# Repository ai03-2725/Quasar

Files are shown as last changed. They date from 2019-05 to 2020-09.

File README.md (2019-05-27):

# Quasar
A replacement controller for the IBM Model M Space Saving keyboard

#### In light of recent claims that I am 100% liable for any of my open source PCBs, I am adding this disclaimer.
#### I provide these PCBs as a reference for designing keyboard PCBs. Using them within your projects will require a will to do research of one's own and to learn the workings of them, potentially fixing issues if they exist.
# I provide these PCBs without liability and without any guarantees regarding functionality, as expressed in the MIT license under which all of these PCBs are licensed.

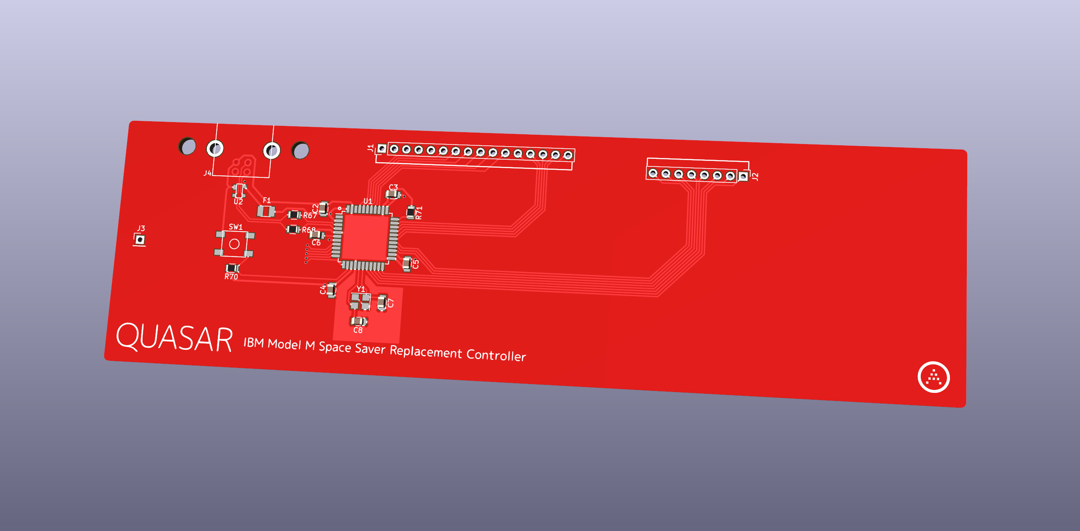
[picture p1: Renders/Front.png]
Render


### Features 
* ATmega32u4-based
* USB-B

### Credits
* Antonizoon's [Model M USB controller research](https://github.com/antonizoon/antonizoon.github.io/wiki/IBM-Model-M-USB-Controller)
* Phosphorglow's [SSK matrix reverse engineering](https://deskthority.net/viewtopic.php?t=8149)
* 9595's [Model M controller dimensions](http://ps-2.kev009.com/ohlandl/keyboard/Keyboard.html)
* Lmorchard's [Model M USB controller research](http://blog.lmorchard.com/2016/02/21/modelm-controller/#secrets-of-2kro-matrices)

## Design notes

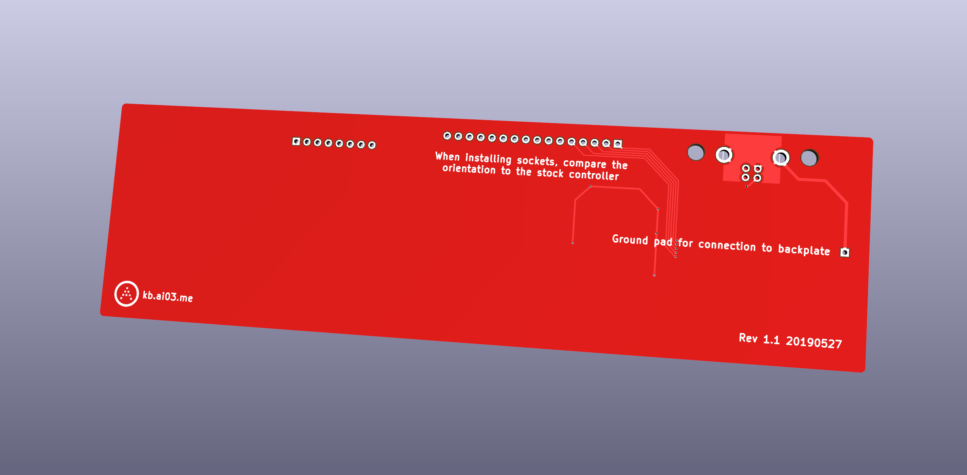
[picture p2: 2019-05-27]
Renders/Back.png

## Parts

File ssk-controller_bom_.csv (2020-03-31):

Component | Description | Part | References | Value | Footprint | Quantity Per PCB | Datasheet
1 | Unpolarized capacitor, small symbol | C_Small | C3 C4 C5 | 0.1uF | C_0805_2012Metric | 3
2 | Unpolarized capacitor, small symbol | C_Small | C2 | 10uF | C_0805_2012Metric | 1
3 | Unpolarized capacitor, small symbol | C_Small | C6 | 1uF | C_0805_2012Metric | 1
4 | Unpolarized capacitor, small symbol | C_Small | C7 C8 | 22pF | C_0805_2012Metric | 2
5 | Unpolarized capacitor, small symbol | C_Small | C1 | 4.7nF | C_0805_2012Metric | 1
6 | Diode, small symbol | D_Small | D1 | 1N4007 | D_SOD-123 | 1 | ~
7 | Resettable fuse, polymeric positive temperature coefficient, small symbol | Polyfuse_Small | F1 | 500mA | Fuse_1206_3216Metric | 1
8 | Generic connector, single row, 01x01, script generated (kicad-library-utils/schlib/autogen/connector/) | Conn_01x01 | J3 | Conn_01x01 | PinHeader_1x01_P2.54mm_Vertical | 1 | ~
9 | Generic connector, single row, 01x08, script generated (kicad-library-utils/schlib/autogen/connector/) | Conn_01x08 | J2 | Conn_01x08 | PinHeader_1x08_P2.54mm_Vertical | 1 | ~
10 | Generic connector, single row, 01x16, script generated (kicad-library-utils/schlib/autogen/connector/) | Conn_01x16 | J1 | Conn_01x16 | PinHeader_1x16_P2.54mm_Vertical | 1 | ~
11 | Generic connector, single row, 01x02, script generated (kicad-library-utils/schlib/autogen/connector/) | Conn_01x02 | J5 | Solenoid | PinHeader_1x02_P2.54mm_Vertical | 1 | ~
12 | Generic connector, single row, 01x03, script generated (kicad-library-utils/schlib/autogen/connector/) | Conn_01x03 | J6 | Solenoid_Signal | JST-SR-3 | 1 | ~
13 | USB Type B connector | USB_B | J4 | USB_B | TE-292304-2 | 1 | ~
14 | N-MOSFET transistor, gate/source/drain | Q_NMOS_GSD | Q1 | Q_NMOS_GSD | SOT-23 | 1 | ~
15 | Resistor, small symbol | R_Small | R2 | 100 | R_0805_2012Metric | 1
16 | Resistor, small symbol | R_Small | R70 | 10k | R_0805_2012Metric | 1
17 | Resistor, small symbol | R_Small | R1 R3 | 1M | R_0805_2012Metric | 2
18 | Resistor, small symbol | R_Small | R71 | 1k | R_0805_2012Metric | 1
19 | Resistor, small symbol | R_Small | R67 R68 | 22 | R_0805_2012Metric | 2
20 | Push button switch, generic, two pins | SW_Push | SW1 | SW_Push | SKQG-1155865 | 1
21 | 16MHz, 16kB Flash, 1.25kB SRAM, 512B EEPROM, USB 2.0, TQFP-44 | ATmega32U4-AU | U1 | ATmega32U4-AU | TQFP-44_10x10mm_P0.8mm | 1 | http://ww1.microchip.com/downloads/en/DeviceDoc/Atmel-7766-8-bit-AVR-ATmega16U4-32U4_Datasheet.pdf
22 |  | PRTR5V0U2X | U2 | PRTR5V0U2X | SOT143B | 1
23 | Four pin crystal, GND on pins 2 and 4 | Crystal_GND24 | Y1 | 16Mhz | Crystal_SMD_3225-4Pin_3.2x2.5mm | 1
Component Groups: | 23
Component Count: | 28
Fitted Components: | 28
Number of PCBs: | 1
Total components: | 28
Schematic Version:
Schematic Date:
BoM Date: | 3/31/2020 9:19:48 AM
Schematic Source: | C:\Users\Ryota Goto\Documents\GitHub\Quasar\ssk-controller.sch
KiCad Version: | Eeschema (5.1.4)-1

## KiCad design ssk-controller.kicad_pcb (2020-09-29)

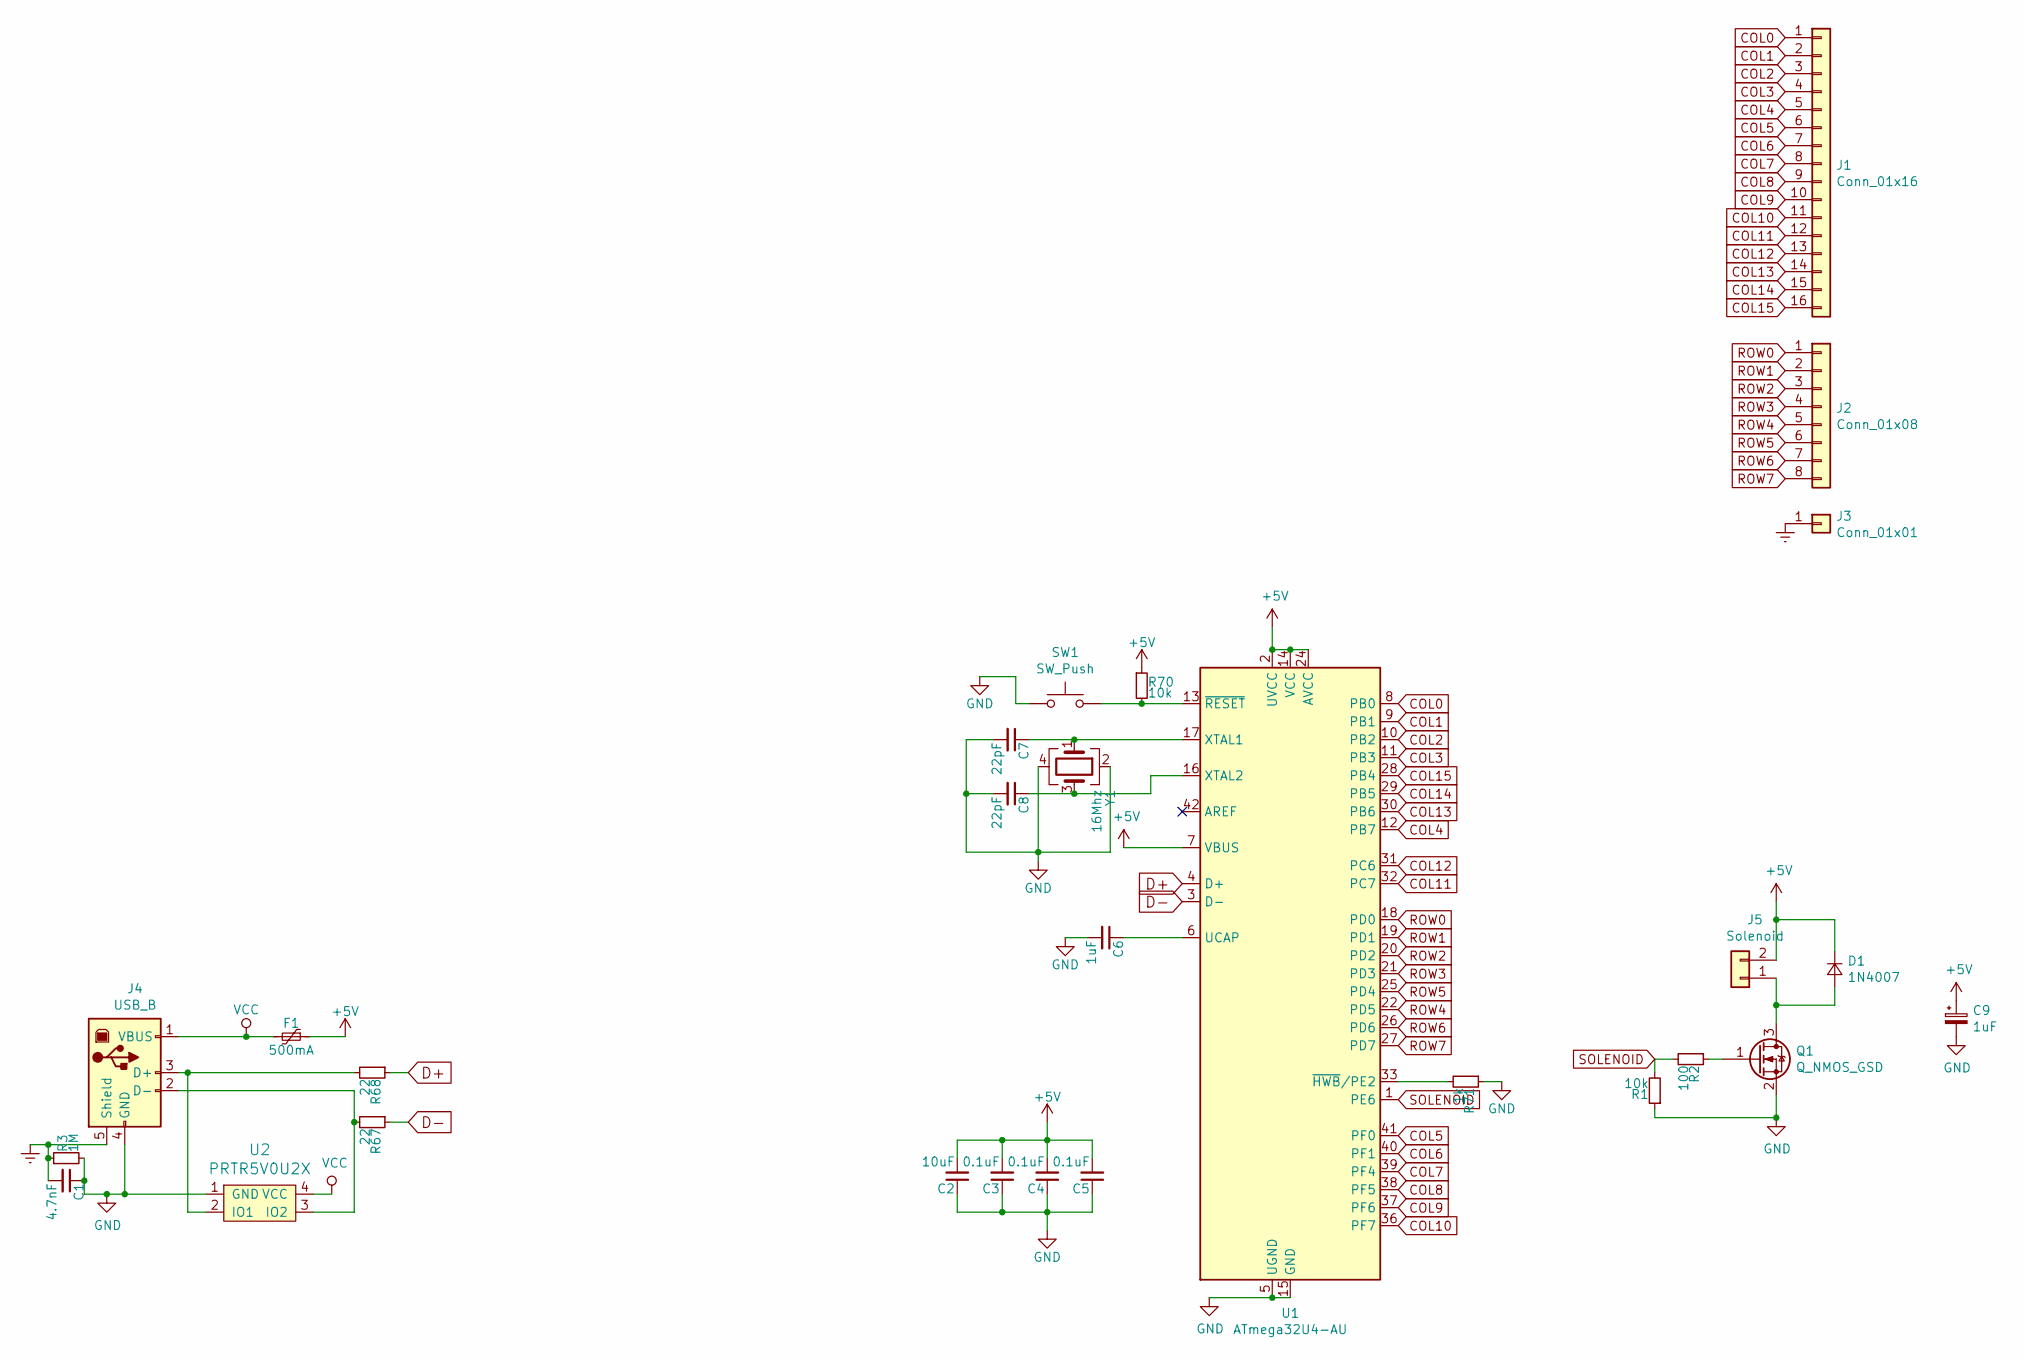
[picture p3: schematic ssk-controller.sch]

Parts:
C1: 4.7nF; C_0805_2012Metric
C2: 10uF; C_0805_2012Metric
C3, C4, C5: 0.1uF; C_0805_2012Metric
C6: 1uF; C_0805_2012Metric
C7, C8: 22pF; C_0805_2012Metric
C9: 1uF; CP_EIA-3216-18_Kemet-A
D1: 1N4007; D_SOD-123
F1: 500mA; Fuse_1206_3216Metric
J1: Conn_01x16; PinHeader_1x16_P2.54mm_Vertical
J2: Conn_01x08; PinHeader_1x08_P2.54mm_Vertical
J3: Conn_01x01; PinHeader_1x01_P2.54mm_Vertical
J4: USB_B; TE-292304-2
J5: Solenoid; PinHeader_1x02_P2.54mm_Vertical
Q1: Q_NMOS_GSD; SOT-23
R1, R70: 10k; R_0805_2012Metric
R2: 100; R_0805_2012Metric
R3: 1M; R_0805_2012Metric
R67, R68: 22; R_0805_2012Metric
R71: 1k; R_0805_2012Metric
SW1: SW_Push; SKQG-1155865
U1: ATmega32U4-AU; TQFP-44_10x10mm_P0.8mm
U2: PRTR5V0U2X; SOT143B
Y1: 16Mhz; Crystal_SMD_3225-4Pin_3.2x2.5mm

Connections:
+5V: C2.2, C3.2, C4.2, C5.2, C9.1, D1.1 (K), F1.1, J5.2, R70.1, U1.2 (UVCC), U1.7 (VBUS), U1.14 (VCC), U1.24 (AVCC), U1.34 (VCC), U1.44 (AVCC)
COL0: J1.1, U1.8 (PB0)
COL1: J1.2, U1.9 (PB1)
COL2: J1.3, U1.10 (PB2)
COL3: J1.4, U1.11 (PB3)
COL4: J1.5, U1.12 (PB7)
COL5: J1.6, U1.41 (PF0)
COL6: J1.7, U1.40 (PF1)
COL7: J1.8, U1.39 (PF4)
COL8: J1.9, U1.38 (PF5)
COL9: J1.10, U1.37 (PF6)
COL10: J1.11, U1.36 (PF7)
COL11: J1.12, U1.32 (PC7)
COL12: J1.13, U1.31 (PC6)
COL13: J1.14, U1.30 (PB6)
COL14: J1.15, U1.29 (PB5)
COL15: J1.16, U1.28 (PB4)
D+: R68.1, U1.4 (D+)
D-: R67.1, U1.3 (D-)
Earth: C1.2, J3.1, J4.5 (Shield), R3.1
GND: C1.1, C2.1, C3.1, C4.1, C5.1, C6.2, C7.2, C8.2, C9.2, J4.4 (GND), Q1.2 (S), R1.1, R3.2, R71.1, SW1.1, U1.5 (UGND), U1.15 (GND), U1.23 (GND), U1.35 (GND), U1.43 (GND), U2.1 (GND), Y1.2, Y1.4
unnamed: C6.1, U1.6 (UCAP)
unnamed: C7.1, U1.17 (XTAL1), Y1.1
unnamed: C8.1, U1.16 (XTAL2), Y1.3
unnamed: D1.2 (A), J5.1, Q1.3 (D)
unnamed: J4.2 (D-), R67.2, U2.3 (IO2)
unnamed: J4.3 (D+), R68.2, U2.2 (IO1)
unnamed: Q1.1 (G), R2.1
unnamed: R70.2, SW1.2, U1.13 (~RESET)
unnamed: R71.2, U1.33 (~HWB~/PE2)
ROW0: J2.1, U1.18 (PD0)
ROW1: J2.2, U1.19 (PD1)
ROW2: J2.3, U1.20 (PD2)
ROW3: J2.4, U1.21 (PD3)
ROW4: J2.5, U1.22 (PD5)
ROW5: J2.6, U1.25 (PD4)
ROW6: J2.7, U1.26 (PD6)
ROW7: J2.8, U1.27 (PD7)
SOLENOID: R1.2, R2.2, U1.1 (PE6)
VCC: F1.2, J4.1 (VBUS), U2.4 (VCC)

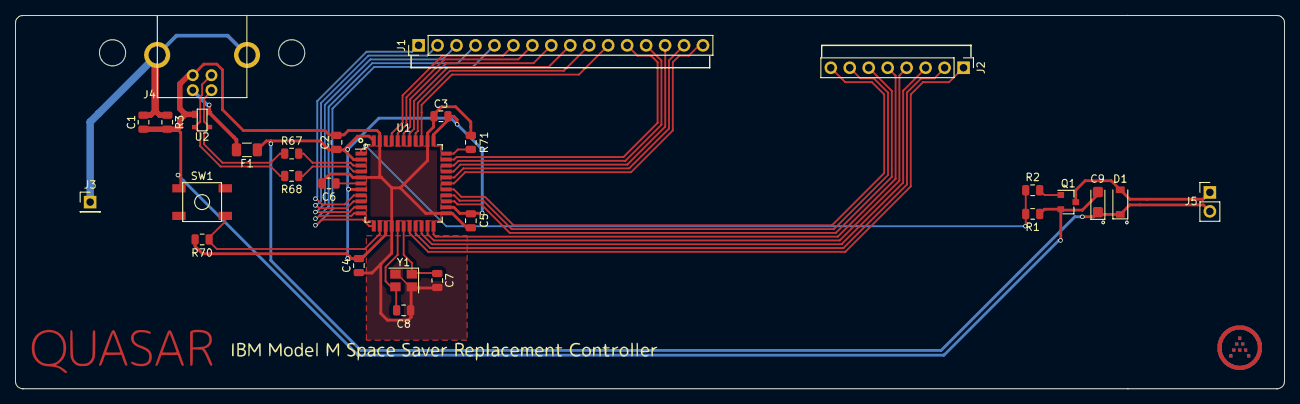
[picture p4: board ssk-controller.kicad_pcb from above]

Board: 2 copper layers, 170.0 x 50.0 mm, 28 parts (0 on the bottom side), 40 nets.

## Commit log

2019-03-13 Begin project
    [ssk-controller.kicad_pcb, ssk-controller.sch, ssk-controller_bom_.csv]
2019-03-13 Finish board
    [ssk-controller-B.Cu.gbl, ssk-controller-B.Fab.gbr, ssk-controller-B.Mask.gbs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]
2019-03-13 Insert render
2019-03-13 Update gerber, minor trace fix
    [ssk-controller-B.Cu.gbl, ssk-controller-B.Fab.gbr, ssk-controller-B.Mask.gbs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]
2019-03-13 Release 1.0
    [ssk-controller-B.Cu.gbl, ssk-controller-B.Fab.gbr, ssk-controller-B.Mask.gbs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]
2019-05-27 New gerbers for USB B
    [ssk-controller-B.Cu.gbl, ssk-controller-B.Mask.gbs, ssk-controller-B.SilkS.gbo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]
2019-05-27 Tune silkscreen
    [ssk-controller-B_Cu.gbl, ssk-controller-B_Fab.gbr, ssk-controller-B_Mask.gbs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]
2020-03-22 Add solenoid support and better ESD handling
    [ssk-controller-B_Cu.gbl, ssk-controller-B_Fab.gbr, ssk-controller-B_Mask.gbs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]
2020-03-22 Cleanup traces
    [ssk-controller-B_Cu.gbl, ssk-controller-B_Mask.gbs, ssk-controller-B_Paste.gbp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]
2020-03-23 Update to 2.0 gerbers
    [ssk-controller-B_Cu.gbl, ssk-controller-B_Mask.gbs, ssk-controller-B_Paste.gbp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]
2020-03-31 Add both 9V and 5V solenoid compat
    [ssk-controller-B_Cu.gbl, ssk-controller-B_Mask.gbs, ssk-controller-B_Paste.gbp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]
2020-03-31 Position and bom files
    [ssk-controller.kicad_pcb, ssk-controller_bom_.csv, ssk-controller_bom_.xlsx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]
2020-09-29 Create JLC files
    [JLCSMT_Sample_BOM1-quasar.xlsx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]
2020-09-29 Remove JST header, focus on 5V direct solenoid
    [JLCSMT_Sample_BOM1-quasar.xlsx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]
2020-09-29 Update to r2.2
    [ssk-controller.kicad_pcb, ssk-controller.sch]
